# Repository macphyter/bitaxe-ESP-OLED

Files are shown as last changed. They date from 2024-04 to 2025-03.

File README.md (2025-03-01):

# bitaxe-ESP-OLED
bitaxe-ESP-OLED is a carrier board for a specific 1.9 inch 170x320 OLED
which is intended to connect to a bitaxe device via the BAP (Bitaxe Accessory Port)
The carrier board contains an ESP32-S3 MCU that drives the display and receives 
status info via UART using the BAP (Bitaxe Accessory Port)

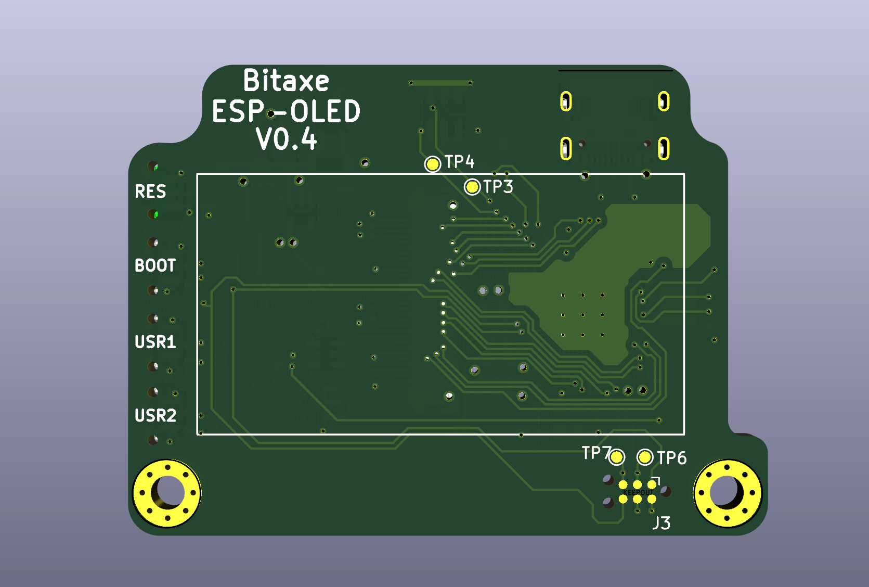
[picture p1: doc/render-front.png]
render-front


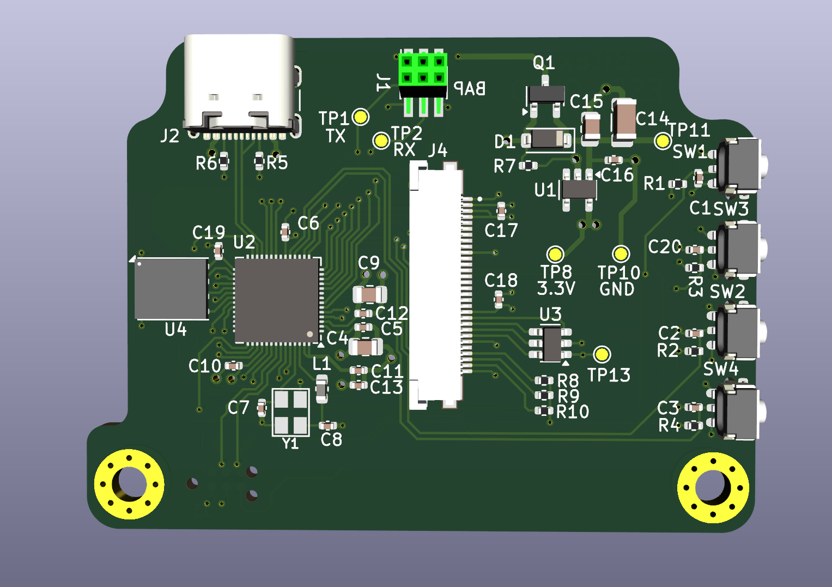
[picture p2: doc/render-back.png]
render-back


Here is the OLED display

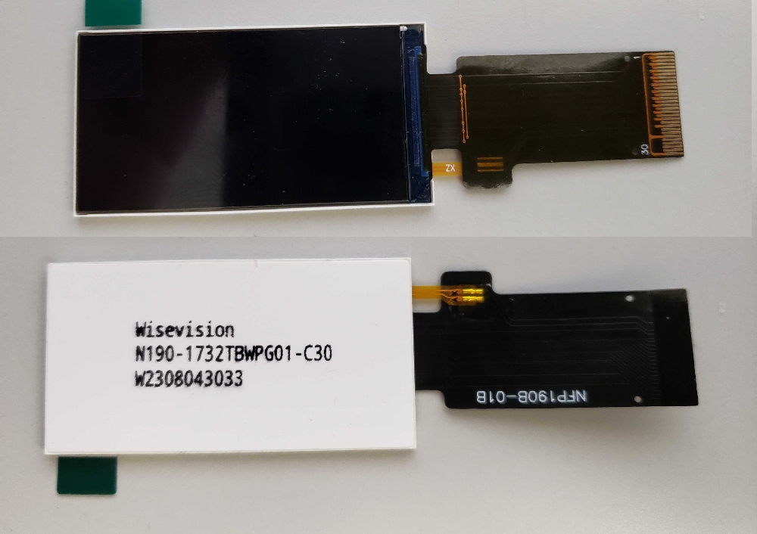
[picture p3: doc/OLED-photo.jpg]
OLED photo


The display attaches to the front of the carrier board using double sided foam tape, and 
the connector wraps around through the notch and attaches to the 30-pin connector on the back.

This OLED display uses a ST7789 controller operates in parallel mode through its 30-pin connector.  
The carrier board uses an ESP32-S3 MCU to drive the OLED.

On the side of the board there is a Reset button, a bootmode button, and two user buttons used for navigating the GUI.

The MCU firmware will display various GUI pages, and the data for these pages will be 
supplied by the bitaxe through the UART.

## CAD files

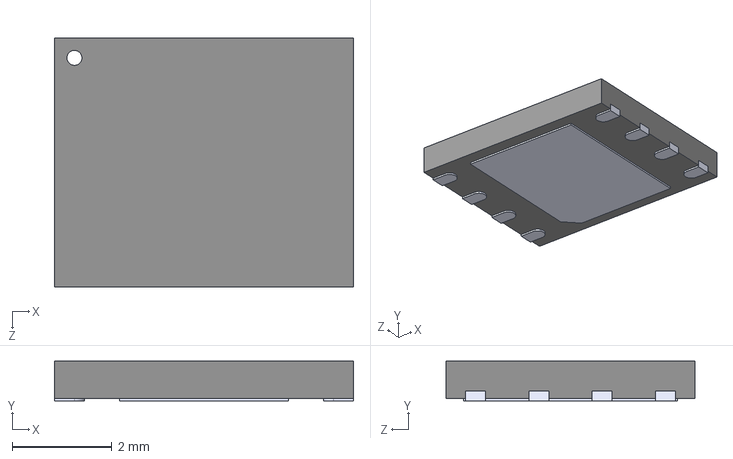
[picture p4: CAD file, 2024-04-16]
3d/W25Q128JVPIQ.step
6.00 x 0.8 x 5.00 mm

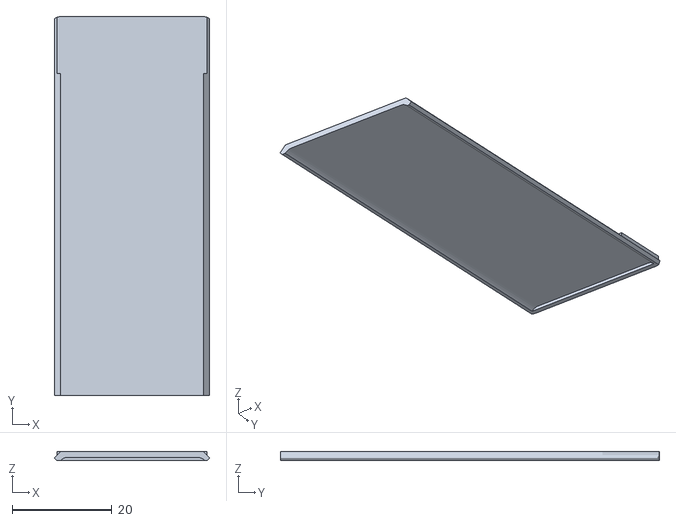
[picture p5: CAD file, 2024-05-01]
Body4.stl
31.2 x 76.0 x 1.80

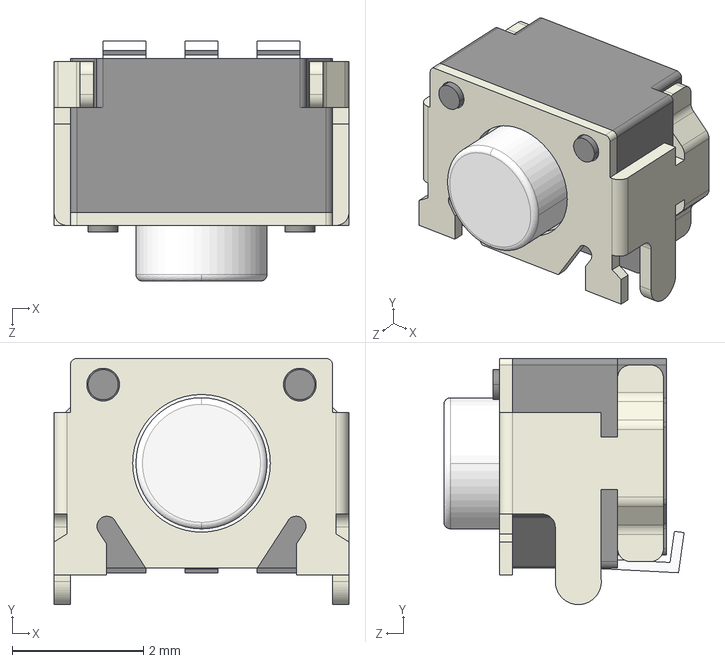
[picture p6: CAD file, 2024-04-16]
3d/TL3340AF160QG.step
4.50 x 3.76 x 3.67 mm

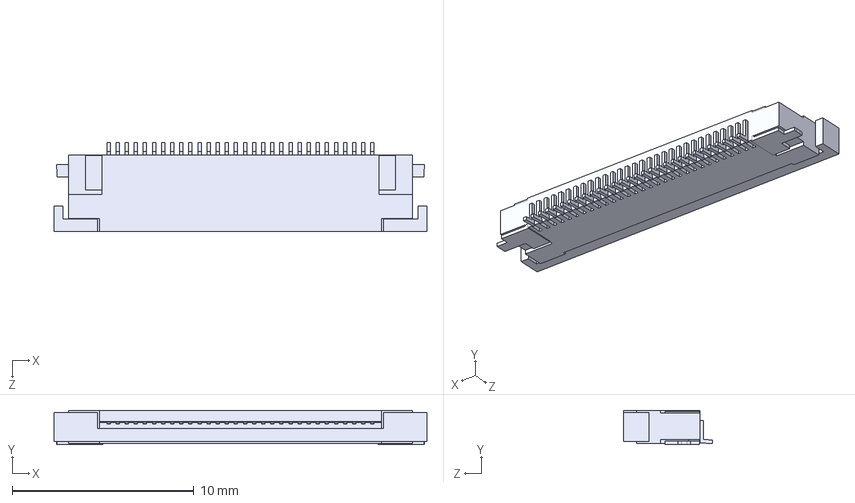
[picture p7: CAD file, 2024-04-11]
3d/SFV30R-4STE1HLF.step
20.5 x 1.87 x 4.90 mm

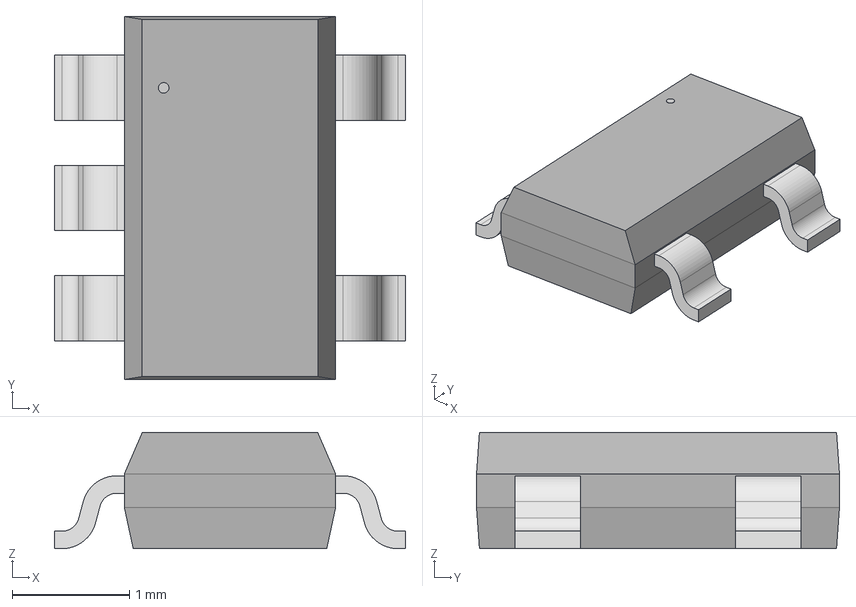
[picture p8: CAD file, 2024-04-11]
3d/TSOT-23-5_RIT.step
3.00 x 3.10 x 0.993 mm

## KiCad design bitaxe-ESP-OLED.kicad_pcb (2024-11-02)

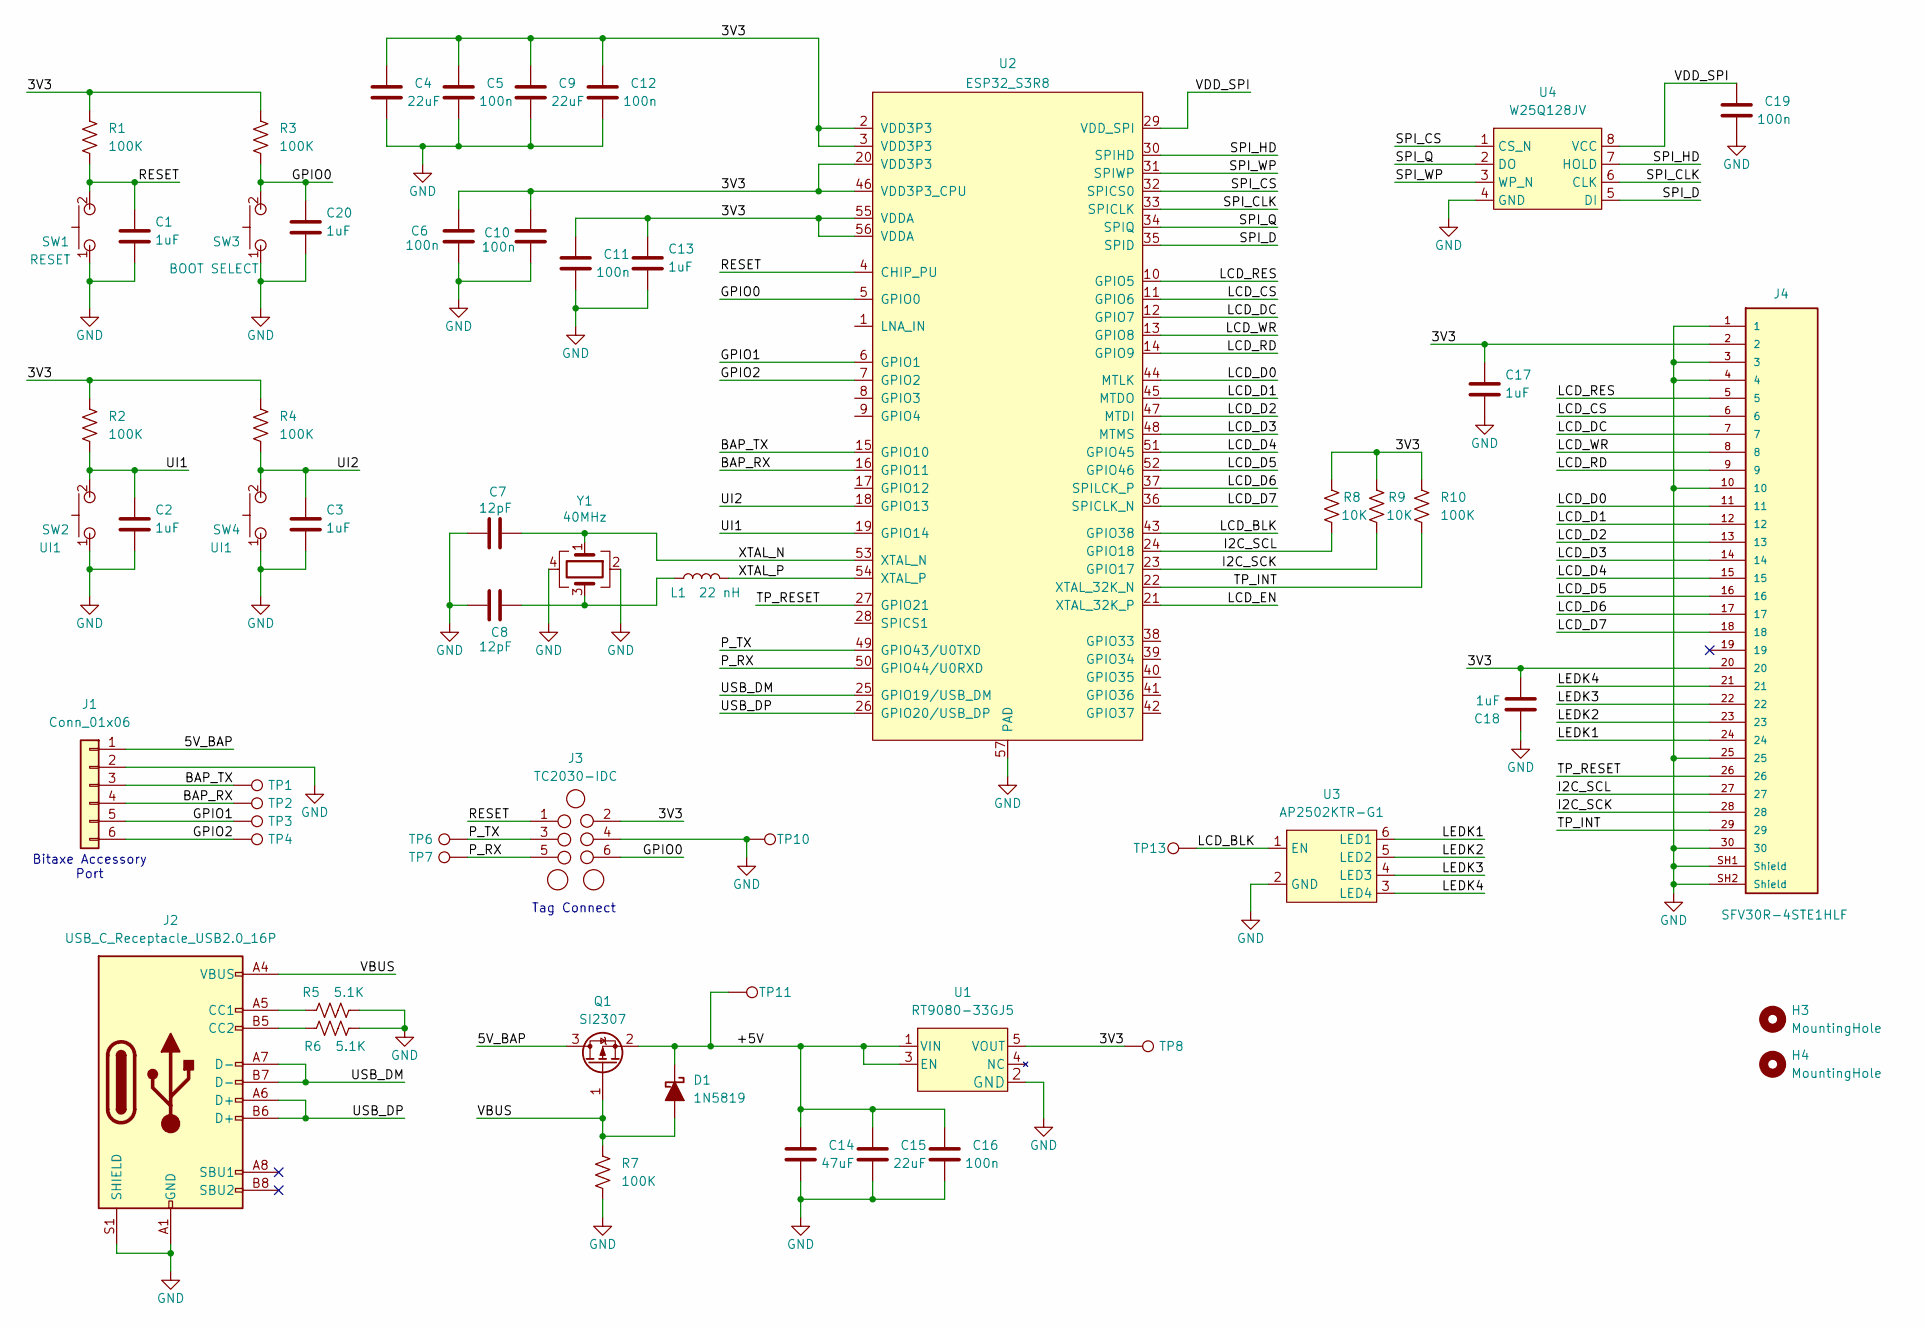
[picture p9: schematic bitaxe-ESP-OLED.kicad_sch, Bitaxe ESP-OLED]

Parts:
C1, C18: 1uF; C_0402_1005Metric; PARTNO EMK105BJ105MV-F
C2, C3, C20: 1uF; C_0402_1005Metric; PARTNO TL3340AF160QG
C4, C9, C15: 22uF; C_0805_2012Metric; PARTNO GRM21BC81C226ME44L
C5, C6, C10, C11, C12, C16, C19: 100n; C_0402_1005Metric; PARTNO KGM05AR71C104KH
C7, C8: 12pF; C_0402_1005Metric; PARTNO CC0100JRNPO7BN120
C13, C17: 1uF; C_0402_1005Metric; PARTNO GRM188R60J105KA01D
C14: 47uF; C_1206_3216Metric; PARTNO MSASE31LBB5476MTNA01
D1: 1N5819; D_SOD-123; PARTNO 1N5819W
H3, H4: MountingHole; MountingHole_3mm_Pad_Via
J1: Conn_01x06; PinSocket_2x03_P1.27mm_Vertical_SMD
J2: USB_C_Receptacle_USB2.0_16P; USB_C_Receptacle_GCT_USB4105-xx-A_16P_TopMnt_Horizontal
J3: TC2030-IDC; Tag-Connect_TC2030-IDC-NL_2x03_P1.27mm_Vertical
J4: SFV30R-4STE1HLF; AMPHENOL_SFV30R-4STE1HLF; PARTREV B
L1: 22 nH; L_0603_1608Metric; PARTNO LRC0603CJ22NGV001T
Q1: SI2307; SOT-23-3; PARTNO SI2307CDS-T1-GE3
R1, R2, R3, R4, R7, R10: 100K; R_0402_1005Metric; PARTNO RC0402FR-07100KL
R5, R6: 5.1K; R_0402_1005Metric; PARTNO RC0402FR-135K1L
R8, R9: 10K; R_0402_1005Metric
SW1, SW3: SWITCH-SPST; TL3340-switch; PARTNO TL3340AF160QG
SW2, SW4: SWITCH-SPST; TL3340-switch; PARTNO TL3301NF160QG-KR
TP1, TP2, TP3, TP4, TP6, TP7, TP8, TP10, TP11, TP13: TestPoint; TestPoint_Pad_D1.0mm
U1: RT9080-33GJ5; TSOT-23-5
U2: ESP32_S3R8; QFN-56-1EP_7x7mm_P0.4mm_EP4x4mm_ThermalVias
U3: AP2502KTR-G1; SOT-23-6; PARTNO AP2502KTR-G1
U4: W25Q128JV; WSON-8-1EP_6x5mm_P1.27mm_EP3.4x4.3mm; PARTNO W25Q128JVPIQ
Y1: 40MHz; RH100-oscillator; PARTNO RH100-40.000-12-F-1010-TR

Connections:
/3V3: C4.1, C5.1, C6.1, C9.1, C10.2, C11.1, C12.1, C13.1, C17.1, C18.2, J3.2, J4.2, J4.20, R1.1, R2.1, R3.1, R4.1, R8.1, R9.1, R10.1, TP8.1, U1.5 (VOUT), U2.2 (VDD3P3), U2.3 (VDD3P3), U2.20 (VDD3P3), U2.46 (VDD3P3_CPU), U2.55 (VDDA), U2.56 (VDDA)
/5V_BAP: J1.1, Q1.3 (D)
/+5V: C14.1, C15.1, C16.1, D1.1 (K), Q1.2 (S), TP11.1, U1.1 (VIN), U1.3 (EN)
/BAP_RX: J1.4, TP2.1, U2.16 (GPIO11)
/BAP_TX: J1.3, TP1.1, U2.15 (GPIO10)
/GPIO0: C20.1, J3.6, R3.2, SW3.2, U2.5 (GPIO0)
/GPIO1: J1.5, TP3.1, U2.6 (GPIO1)
/GPIO2: J1.6, TP4.1, U2.7 (GPIO2)
/I2C_SCK: J4.28, R9.2, U2.23 (GPIO17)
/I2C_SCL: J4.27, R8.2, U2.24 (GPIO18)
/LCD_BLK: TP13.1, U2.43 (GPIO38), U3.1 (EN)
/LCD_CS: J4.6, U2.11 (GPIO6)
/LCD_D0: J4.11, U2.44 (MTLK)
/LCD_D1: J4.12, U2.45 (MTDO)
/LCD_D2: J4.13, U2.47 (MTDI)
/LCD_D3: J4.14, U2.48 (MTMS)
/LCD_D4: J4.15, U2.51 (GPIO45)
/LCD_D5: J4.16, U2.52 (GPIO46)
/LCD_D6: J4.17, U2.37 (SPILCK_P)
/LCD_D7: J4.18, U2.36 (SPICLK_N)
/LCD_DC: J4.7, U2.12 (GPIO7)
/LCD_EN: U2.21 (XTAL_32K_P)
/LCD_RD: J4.9, U2.14 (GPIO9)
/LCD_RES: J4.5, U2.10 (GPIO5)
/LCD_WR: J4.8, U2.13 (GPIO8)
/LEDK1: J4.24, U3.6 (LED1)
/LEDK2: J4.23, U3.5 (LED2)
/LEDK3: J4.22, U3.4 (LED3)
/LEDK4: J4.21, U3.3 (LED4)
/P_RX: J3.5, TP7.1, U2.50 (GPIO44/U0RXD)
/P_TX: J3.3, TP6.1, U2.49 (GPIO43/U0TXD)
/RESET: C1.1, J3.1, R1.2, SW1.2, U2.4 (CHIP_PU)
/SPI_CLK: U2.33 (SPICLK), U4.6 (CLK)
/SPI_CS: U2.32 (SPICS0), U4.1 (CS_N)
/SPI_D: U2.35 (SPID), U4.5 (DI)
/SPI_HD: U2.30 (SPIHD), U4.7 (HOLD)
/SPI_Q: U2.34 (SPIQ), U4.2 (DO)
/SPI_WP: U2.31 (SPIWP), U4.3 (WP_N)
/TP_INT: J4.29, R10.2, U2.22 (XTAL_32K_N)
/TP_RESET: J4.26, U2.27 (GPIO21)
/UI1: C2.1, R2.2, SW2.2, U2.19 (GPIO14)
/UI2: C3.1, R4.2, SW4.2, U2.18 (GPIO13)
/USB_DM: J2.A7 (D-), J2.B7 (D-), U2.25 (GPIO19/USB_DM)
/USB_DP: J2.A6 (D+), J2.B6 (D+), U2.26 (GPIO20/USB_DP)
/VBUS: D1.2 (A), J2.A4 (VBUS), J2.A9 (VBUS), J2.B4 (VBUS), J2.B9 (VBUS), Q1.1 (G), R7.1
/VDD_SPI: C19.1, U2.29 (VDD_SPI), U4.8 (VCC)
/XTAL_N: C7.2, U2.53 (XTAL_N), Y1.1
/XTAL_P: L1.2, U2.54 (XTAL_P)
GND: C1.2, C2.2, C3.2, C4.2, C5.2, C6.2, C7.1, C8.1, C9.2, C10.1, C11.2, C12.2, C13.2, C14.2, C15.2, C16.2, C17.2, C18.1, C19.2, C20.2, J1.2, J2.A1 (GND), J2.A12 (GND), J2.B1 (GND), J2.B12 (GND), J2.S1 (SHIELD), J3.4, J4.1, J4.3, J4.4, J4.10, J4.25, J4.30, J4.SH1 (Shield), J4.SH2 (Shield), R5.2, R6.2, R7.2, SW1.1, SW2.1, SW3.1, SW4.1, TP10.1, U1.2 (GND), U2.57 (PAD), U3.2 (GND), U4.4 (GND), Y1.2, Y1.4
unnamed: C8.2, L1.1, Y1.3
unnamed: J2.A5 (CC1), R5.1
unnamed: J2.B5 (CC2), R6.1

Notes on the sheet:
Tag Connect
Bitaxe Accessory Port

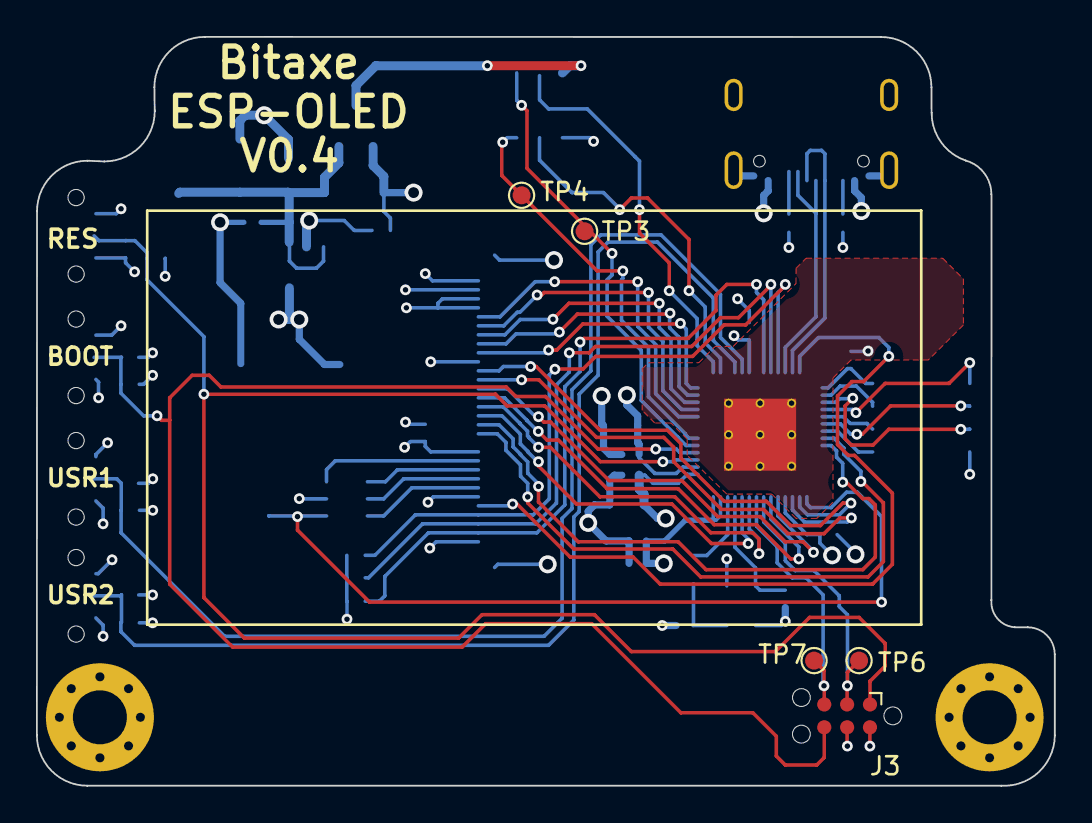
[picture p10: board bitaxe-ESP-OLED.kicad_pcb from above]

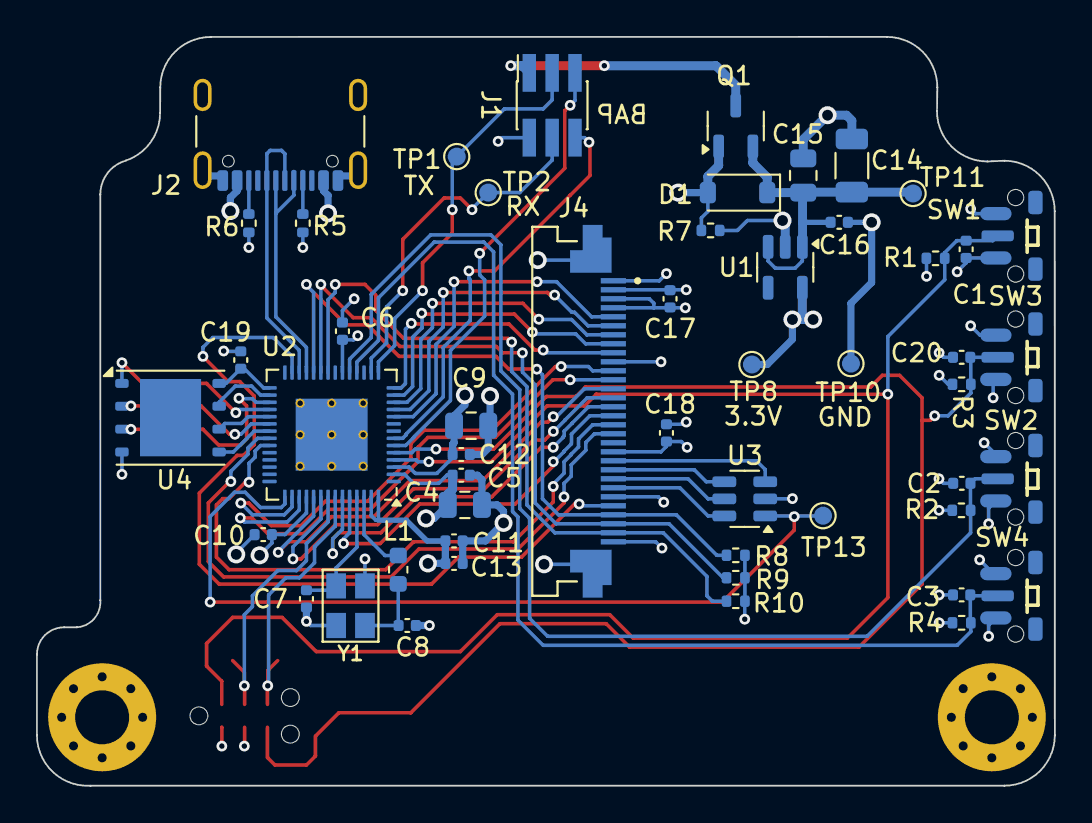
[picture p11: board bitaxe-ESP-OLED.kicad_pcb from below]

Board: 4 copper layers, 56.6 x 41.6 mm, 58 parts (51 on the bottom side), 51 nets.

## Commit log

2024-04-13 very rough routing
    [bitaxe-ESP-OLED.kicad_pcb]
2024-04-15 main MCU routing to OLED connector
    [bitaxe-ESP-OLED.kicad_pcb, bitaxe-ESP-OLED.kicad_sch]
2024-04-16 finish most of the routing
    [bitaxe-ESP-OLED.kicad_pcb, bitaxe-ESP-OLED.kicad_sch]
2024-04-16 Finish up routing
    [TL3340AF160QG.step, W25Q128JVPIQ.step, bitaxe-ESP-OLED.kicad_pcb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]
2024-04-17 commit version 0.1
    [bitaxe-ESP-OLED-B_Cu.gbr, bitaxe-ESP-OLED-B_Mask.gbr, bitaxe-ESP-OLED-B_Paste.gbr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]
2024-05-01 reverse BAP port
    [Body4.stl, NerdNOS_BOM.csv, bitaxe-ESP-OLED.kicad_pcb]
2024-05-01 fix outline
    [bitaxe-ESP-OLED.kicad_pcb]
2024-05-05 more fpc room
    [bitaxe-ESP-OLED.kicad_pcb, bitaxe-ESP-OLED.kicad_sch]
2024-05-18 remove KiCad lock file
2024-05-18 link bitaxe library
    [bitaxe-ESP-OLED.kicad_pcb]
2024-05-23 moved switches
    [bitaxe-ESP-OLED.kicad_pcb, bitaxe-ESP-OLED.kicad_sch]
2024-11-02 Expand copper pour underneath MCU
    [bitaxe-ESP-OLED-B_Cu.gbr, bitaxe-ESP-OLED-B_Mask.gbr, bitaxe-ESP-OLED-B_Paste.gbr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]
2025-03-01 update PCB renderings
